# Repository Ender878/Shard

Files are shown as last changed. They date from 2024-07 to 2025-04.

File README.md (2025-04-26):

# Shard - Custom ESP32 S3 Board :electron:

Shard_png2

**Shard** is an open source **ESP32 S3** board that I designed as a summer project to learn more about electronics and PCB design.

## Core features:

- 16MB Flash
- WiFi and Bluethoot capabilities
- Built-in Neopixel RGB LED
- 21 configurable GPIO pins
- Up to 16V for external Power supply
- UART & Configurable SPI and I2C pins

The board itself is pretty small, 4.6x4.8cm and doesn't have mounting holes unfortunately. It is designed to be an all-feature development board for prototyping.

## Programming

### Uploading

The board doesn't come with a **USB-UART bridge**, so the firmware uploading requires user input:

- When the uploading process starts, hold the **RESET** button
- Immediately after you pressed it, press the **BOOT** button and then release the **RESET** button
- After the code is uploaded, press the **RESET** button again to exit Download Mode, so that the board can execute the code.

### Programming with Arduino IDE 2

To program this board with the **Arduino IDE**, you have to:
- Install the "esp32" board manager.
- then select the **UM-PROS3** board 
- when uploading, follow the steps listed in the **[Uploading](#uploading)** section.

### Programming with PlatformIO (recommended)

To program this board with **PlatformIO**, you should configure the **platformio.ini** file as follows:

~~~ini
[env:esp32-s3-devkitc-1]
platform = espressif32
board = shard
framework = arduino
~~~

I made a custom **board** config file for PlatformIO that specifies all the board's specifications. To use it, create a folder called **boards** and copy [this file](./shard.json) under it.

Also, this is the partition I used:

~~~csv
# Name,   Type, SubType, Offset,  Size, Flags
nvs,      data, nvs,     0x9000,  0x5000,
otadata,  data, ota,     0xe000,  0x2000,
app0,     app,  ota_0,   0x10000, 0x700000,
app1,     app,  ota_1,   0x710000,0x700000,
spiffs,   data, spiffs,  0xe10000,0x1F0000,
~~~

PlatformIO should find the board automatically. When uploading, still follow the steps in the **[Uploading](#uploading)** section.

## Reference

To design this board, I mainly referred to the Espressif's [ESP32-S3 Hardware Design Guidelines](https://docs.espressif.com/projects/esp-hardware-design-guidelines/en/latest/esp32s3/esp-hardware-design-guidelines-en-master-esp32s3.pdf).

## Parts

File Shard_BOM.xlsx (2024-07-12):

Comment | Designator | Footprint | JLCPCB Part #（optional）
~ | ANT1 | RF_Antenna:Texas_SWRA117D_2.4GHz_Right
1uF | C1 | Capacitor_SMD:C_0201_0603Metric | C5209398
2.2uF | C2 | Capacitor_SMD:C_0402_1005Metric | C386078
1uF | C3 | Capacitor_SMD:C_0201_0603Metric | C5209398
10nF | C4 | Capacitor_SMD:C_0201_0603Metric | C312126
10uF | C5 | Capacitor_SMD:C_0805_2012Metric | C100083
1uF | C6 | Capacitor_SMD:C_0402_1005Metric | C325464
0.1uF | C7 | Capacitor_SMD:C_0402_1005Metric | C312123
0.1uF | C8 | Capacitor_SMD:C_0402_1005Metric | C312123
1uF | C9 | Capacitor_SMD:C_0201_0603Metric | C5209398
0.1uF | C10 | Capacitor_SMD:C_0201_0603Metric | C312124
0.1uF | C11 | Capacitor_SMD:C_0201_0603Metric | C312124
0.1uF | C12 | Capacitor_SMD:C_0201_0603Metric | C312124
1uF | C13 | Capacitor_SMD:C_0201_0603Metric | C5209398
2.2uF | C14 | Capacitor_SMD:C_0402_1005Metric | C386078
1uF | C15 | Capacitor_SMD:C_0201_0603Metric | C5209398
0.1uF | C16 | Capacitor_SMD:C_0201_0603Metric | C312124
20pF | C17 | Capacitor_SMD:C_0201_0603Metric | C426053
20pF | C18 | Capacitor_SMD:C_0201_0603Metric | C426053
3pF | C19 | Capacitor_SMD:C_0201_0603Metric | C508850
2.7pF | C20 | Capacitor_SMD:C_0402_1005Metric | C386137
SS34 | D1 | Diode_SMD:D_SMA | C8678
SS34 | D2 | Diode_SMD:D_SMA | C8678
LED | D3 | LED_SMD:LED_0805_2012Metric | C2297
WS2812B | D4 | LED_SMD:LED_WS2812B-2020_PLCC4_2.0x2.0mm | C965555
USB_C_Receptacle_USB2.0_16P | J1 | Connector_USB:USB_C_Receptacle_GCT_USB4105-xx-A_16P_TopMnt_Horizontal | C2927038
Conn_01x08 | J2 | Connector_PinSocket_2.54mm:PinSocket_1x08_P2.54mm_Vertical
Conn_01x08 | J3 | Connector_PinSocket_2.54mm:PinSocket_1x08_P2.54mm_Vertical
Conn_01x08 | J4 | Connector_PinSocket_2.54mm:PinSocket_1x08_P2.54mm_Vertical
Conn_01x08 | J5 | Connector_PinSocket_2.54mm:PinSocket_1x08_P2.54mm_Vertical
2nH | L1 | Inductor_SMD:L_0201_0603Metric | C415347
2.4nH | L2 | Inductor_SMD:L_0201_0603Metric | C87200
5.1k | R1 | Resistor_SMD:R_0402_1005Metric | C294638
5.1k | R2 | Resistor_SMD:R_0402_1005Metric | C294638
220 | R3 | Resistor_SMD:R_0805_2012Metric | C2771036
10k | R4 | Resistor_SMD:R_0402_1005Metric | C3152101
100k | R5 | Resistor_SMD:R_1210_3225Metric | C304940
0 | R6 | Resistor_SMD:R_0201_0603Metric | C965347
0 | R7 | Resistor_SMD:R_0201_0603Metric | C965347
0 | R8 | Resistor_SMD:R_0201_0603Metric | C965347
0 | R9 | Resistor_SMD:R_0201_0603Metric | C965347
0 | R10 | Resistor_SMD:R_0201_0603Metric | C965347
22 | R11 | Resistor_SMD:R_0201_0603Metric | C306975
499 | R12 | Resistor_SMD:R_0805_2012Metric | C17722
BOOT | BOOT | Button_Switch_SMD:SW_Push_SPST_NO_Alps_SKRK | C720477
RESET | RESET | Button_Switch_SMD:SW_Push_SPST_NO_Alps_SKRK | C720477
ESP32-S3 | U1 | Package_DFN_QFN:QFN-56-1EP_7x7mm_P0.4mm_EP4x4mm | C2913194
USBLC6-2P6 | U2 | Package_TO_SOT_SMD:SOT-666 | C2827693
TLV76733DRVx | U3 | Package_SON:WSON-6-1EP_2x2mm_P0.65mm_EP1x1.6mm_ThermalVias | C2848334
TLV76733DRVx | U4 | Package_SON:WSON-6-1EP_2x2mm_P0.65mm_EP1x1.6mm_ThermalVias | C2848334
W25Q128JVS | U5 | Package_SO:SOIC-8_5.23x5.23mm_P1.27mm | C97521
40Mhz | Y1 | Crystal:Crystal_SMD_2520-4Pin_2.5x2.0mm | C409423

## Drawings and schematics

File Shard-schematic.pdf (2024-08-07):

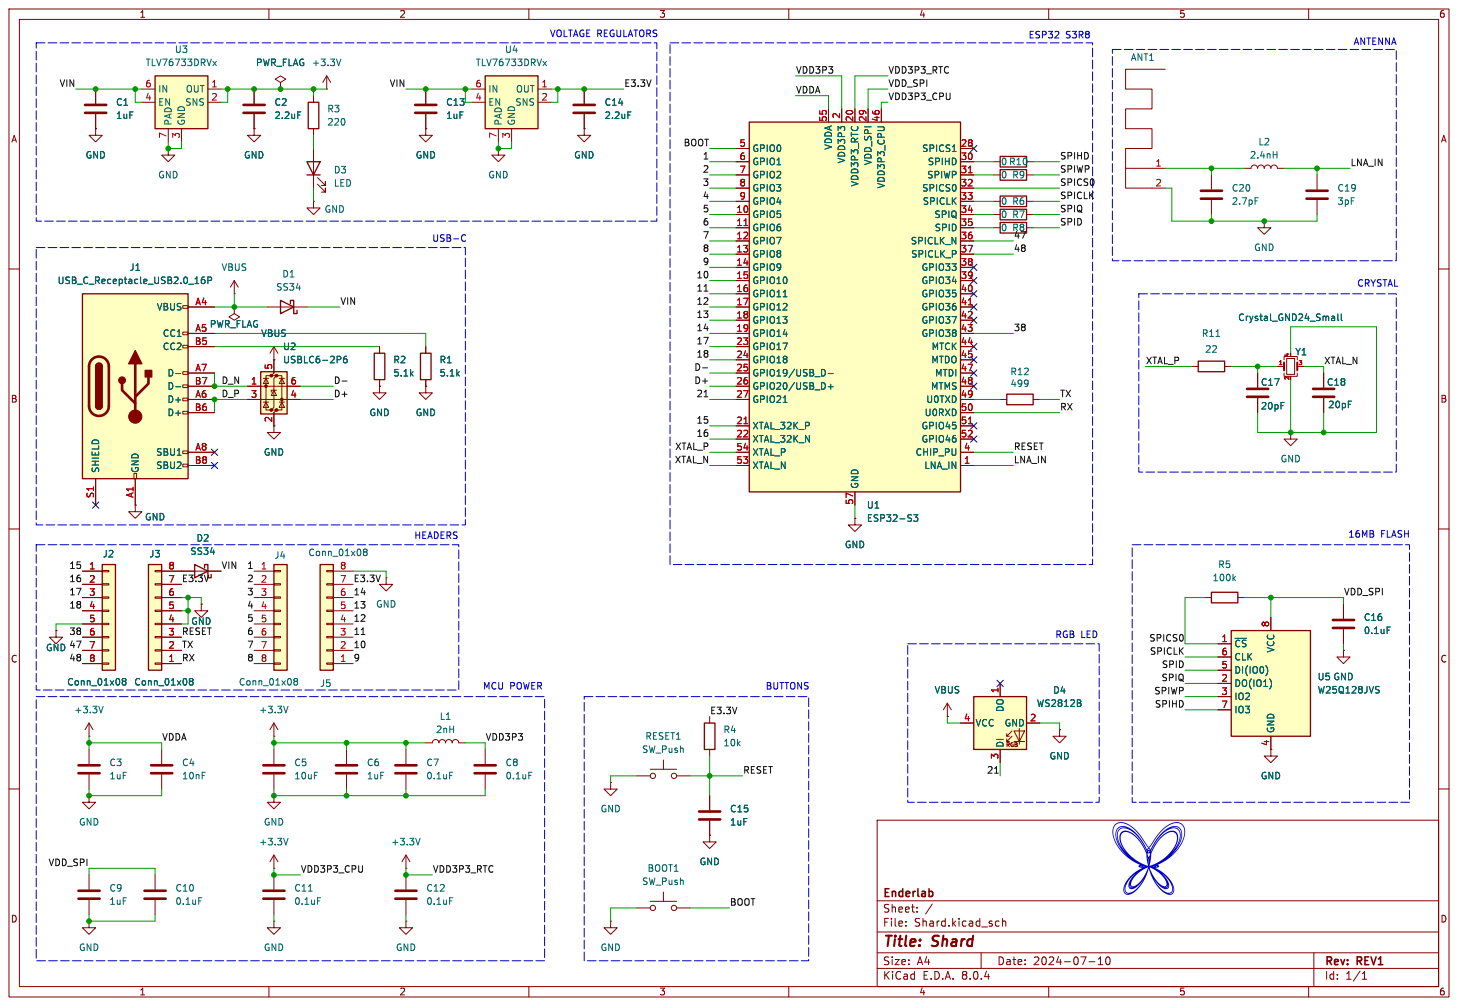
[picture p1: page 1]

2 VDD3P3_RTC 20 XTAL_32K_P 21 XTAL_32K_N 22 GPIO17 23 GPIO18 24 GPIO19/USB_D- 25 GPIO20/USB_D+ 26 GPIO21 27 SPICS1 28 VDD_SPI 29 SPIHD 30 SPIWP 31 SPICS0 32 SPICLK 33 SPIQ 34 SPID 35 SPICLK_P 37 GPIO33 38 GPIO34 39 CHIP_PU 4 GPIO35 40 GPIO36 41 GPIO37 42 GPIO38 43 MTCK 44 VDD3P3_CPU 46 MTDI 47 MTMS 48 U0TXD 49 GPIO0 5 U0RXD 50 GPIO46 52 XTAL_N 53 XTAL_P 54 VDDA 55 GND 57 GPIO1 6 GPIO2 7 GPIO3 8 GPIO4 9 GND GND GND GND GND

2 VDD3P3_RTC 20 XTAL_32K_P 21 XTAL_32K_N 22 GPIO17 23 GPIO18 24 GPIO19/USB_D- 25 GPIO20/USB_D+ 26 GPIO21 27 SPICS1 28 VDD_SPI 29 SPIHD 30 SPIWP 31 SPICS0 32 SPICLK 33 SPIQ 34 SPID 35 SPICLK_P 37 GPIO33 38 GPIO34 39 CHIP_PU 4 GPIO35 40 GPIO36 41 GPIO37 42 GPIO38 43 MTCK 44 VDD3P3_CPU 46 MTDI 47 MTMS 48 U0TXD 49 GPIO0 5 U0RXD 50 GPIO46 52 XTAL_N 53 XTAL_P 54 VDDA 55 GND 57 GPIO1 6 GPIO2 7 GPIO3 8 GPIO4 9 U1ESP32-S3

1 GND 2 DI 3 VCC 4 D4 WS2812B GND GND

1 GND 2 DI 3 VCC 4 GND

File: Shard.kicad_sch Sheet: / Enderlab

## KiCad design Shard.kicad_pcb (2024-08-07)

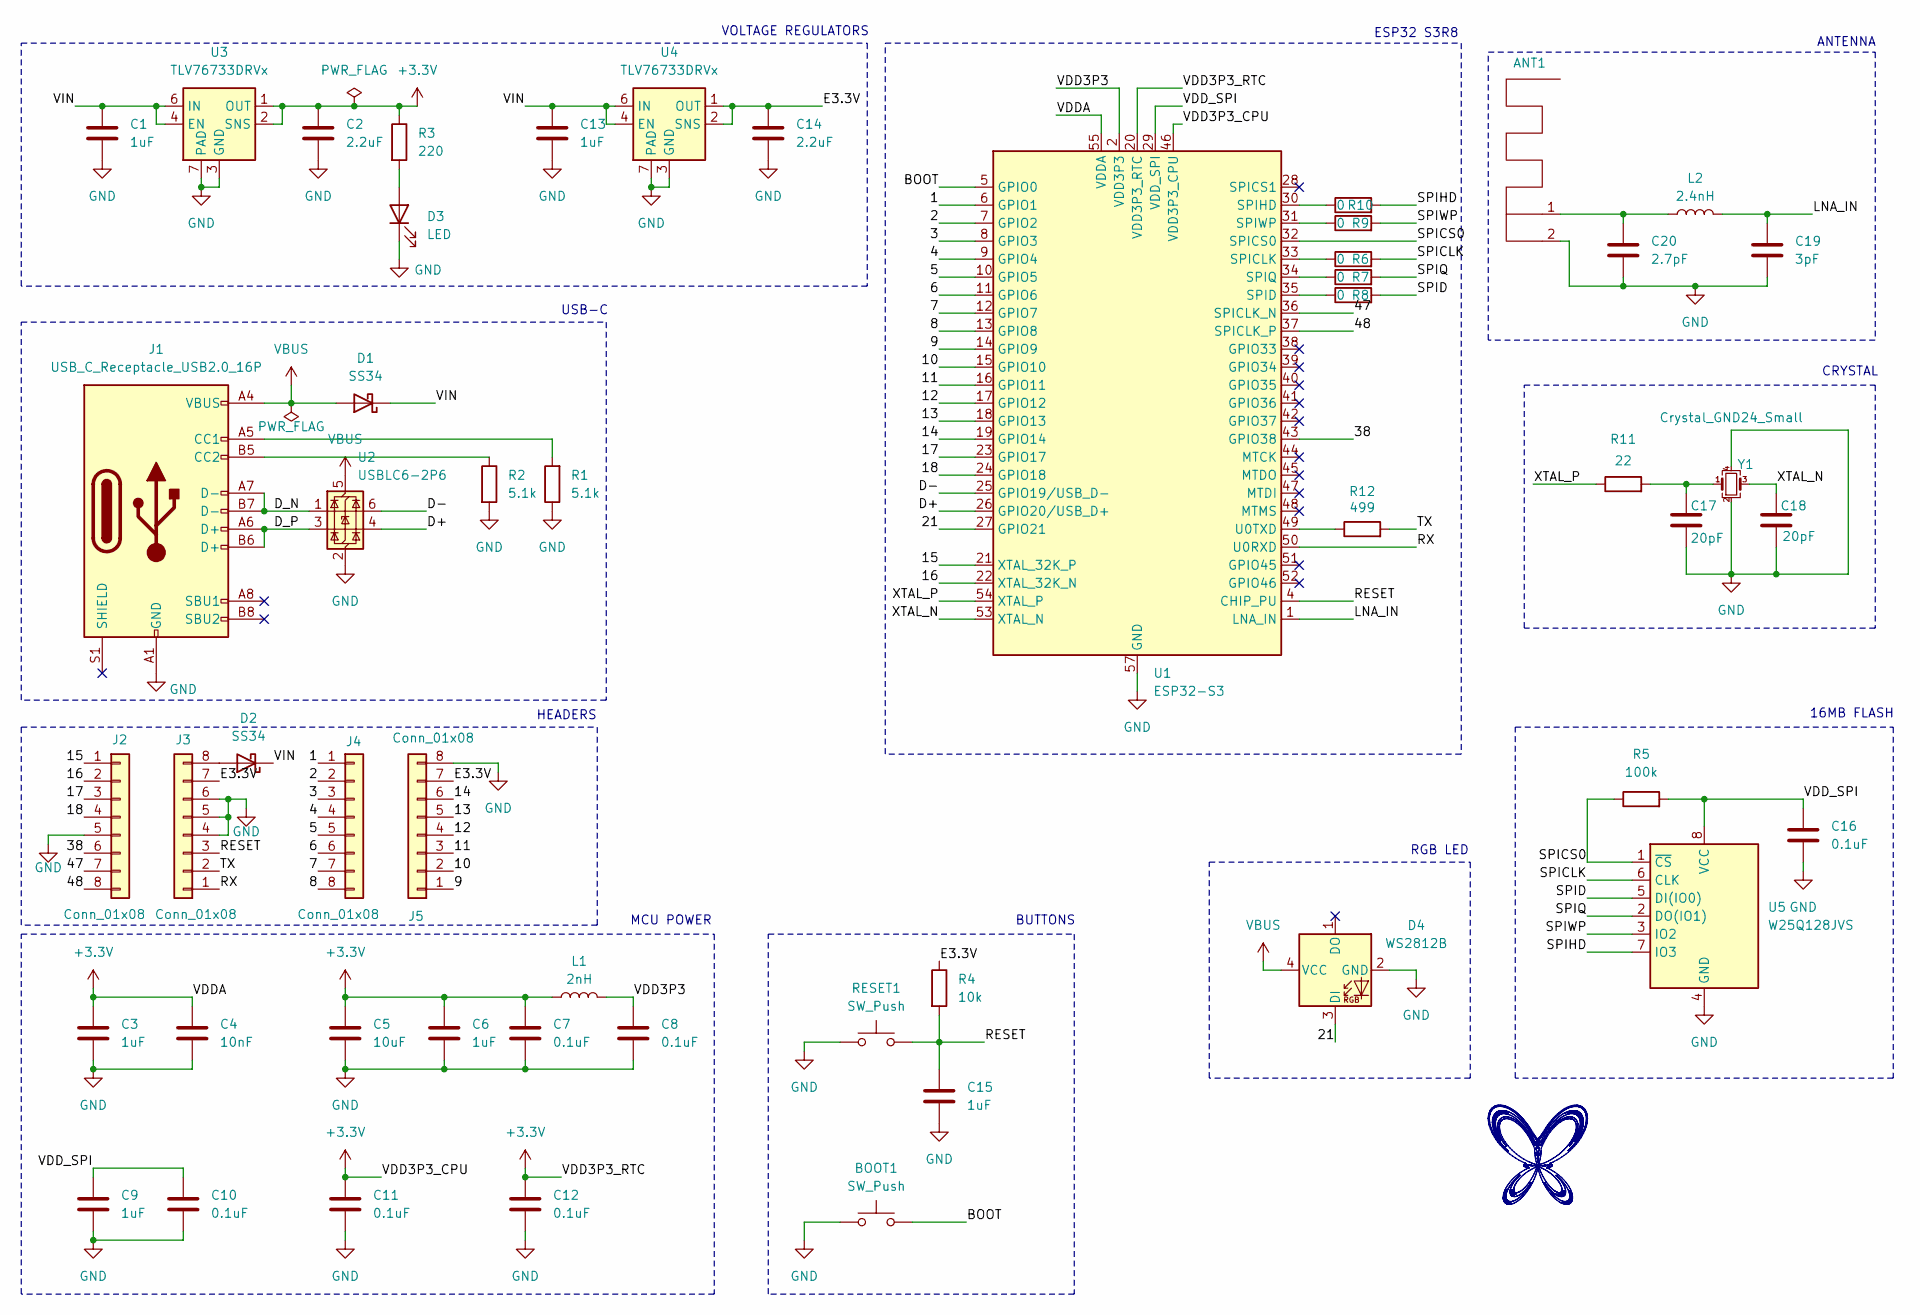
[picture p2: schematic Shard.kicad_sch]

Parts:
ANT1: Texas_SWRA117D_2.4GHz_Right
BOOT1: SW_Push; SW_Push_SPST_NO_Alps_SKRK
C1, C3, C9, C13, C15: 1uF; C_0201_0603Metric
C2, C14: 2.2uF; C_0402_1005Metric
C4: 10nF; C_0201_0603Metric
C5: 10uF; C_0805_2012Metric
C6: 1uF; C_0402_1005Metric
C7, C8: 0.1uF; C_0402_1005Metric
C10, C11, C12, C16: 0.1uF; C_0201_0603Metric
C17, C18: 20pF; C_0201_0603Metric
C19: 3pF; C_0201_0603Metric
C20: 2.7pF; C_0402_1005Metric
D1, D2: SS34; D_SMA
D3: LED; LED_0805_2012Metric
D4: WS2812B; LED_WS2812B-2020_PLCC4_2.0x2.0mm
J1: USB_C_Receptacle_USB2.0_16P; USB_C_Receptacle_GCT_USB4105-xx-A_16P_TopMnt_Horizontal
J2, J3, J4, J5: Conn_01x08; PinSocket_1x08_P2.54mm_Vertical
L1: 2nH; L_0201_0603Metric
L2: 2.4nH; L_0201_0603Metric
R1, R2: 5.1k; R_0402_1005Metric
R3: 220; R_0805_2012Metric
R4: 10k; R_0402_1005Metric
R5: 100k; R_1210_3225Metric
R6, R7, R8, R9, R10: 0; R_0201_0603Metric
R11: 22; R_0201_0603Metric
R12: 499; R_0805_2012Metric
RESET1: SW_Push; SW_Push_SPST_NO_Alps_SKRK
U1: ESP32-S3; QFN-56-1EP_7x7mm_P0.4mm_EP4x4mm
U2: USBLC6-2P6; SOT-666
U3, U4: TLV76733DRVx; WSON-6-1EP_2x2mm_P0.65mm_EP1x1.6mm_ThermalVias
U5: W25Q128JVS; SOIC-8_5.23x5.23mm_P1.27mm
Y1: Crystal_GND24_Small; Crystal_SMD_2520-4Pin_2.5x2.0mm

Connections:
+3.3V: C2.1, C3.1, C4.1, C5.1, C6.1, C7.1, C11.1, C12.1, L1.1, R3.1, U1.20 (VDD3P3_RTC), U1.46 (VDD3P3_CPU), U1.55 (VDDA), U1.56 (VDDA), U3.1 (OUT), U3.2 (SNS)
/1: J4.1, U1.6 (GPIO1)
/2: J4.2, U1.7 (GPIO2)
/3: J4.3, U1.8 (GPIO3)
/4: J4.4, U1.9 (GPIO4)
/5: J4.5, U1.10 (GPIO5)
/6: J4.6, U1.11 (GPIO6)
/7: J4.7, U1.12 (GPIO7)
/8: J4.8, U1.13 (GPIO8)
/9: J5.1, U1.14 (GPIO9)
/10: J5.2, U1.15 (GPIO10)
/11: J5.3, U1.16 (GPIO11)
/12: J5.4, U1.17 (GPIO12)
/13: J5.5, U1.18 (GPIO13)
/14: J5.6, U1.19 (GPIO14)
/15: J2.1, U1.21 (XTAL_32K_P)
/16: J2.2, U1.22 (XTAL_32K_N)
/17: J2.3, U1.23 (GPIO17)
/18: J2.4, U1.24 (GPIO18)
/21: D4.3 (DI), U1.27 (GPIO21)
/38: J2.6, U1.43 (GPIO38)
/47: J2.7, U1.36 (SPICLK_N)
/48: J2.8, U1.37 (SPICLK_P)
/BOOT: BOOT1.2, U1.5 (GPIO0); also elsewhere on the board
/D+: U1.26 (GPIO20/USB_D+), U2.4 (I/O2)
/D-: U1.25 (GPIO19/USB_D-), U2.6 (I/O1)
/D_N: J1.A7 (D-), J1.B7 (D-), U2.1 (I/O1)
/D_P: J1.A6 (D+), J1.B6 (D+), U2.3 (I/O2)
/E3.3V: C14.1, J3.7, J5.7, R4.1, U4.1 (OUT), U4.2 (SNS)
/LNA_IN: C19.1, L2.2, U1.1 (LNA_IN)
/RESET: C15.1, J3.3, R4.2, RESET1.2, U1.4 (CHIP_PU); also elsewhere on the board
/RX: J3.1, U1.50 (U0RXD)
/SPICLK: R6.2, U5.6 (CLK)
/SPICS0: R5.1, U1.32 (SPICS0), U5.1 (~CS)
/SPID: R8.2, U5.5 (DI(IO0))
/SPIHD: R10.2, U5.7 (IO3)
/SPIQ: R7.2, U5.2 (DO(IO1))
/SPIWP: R9.2, U5.3 (IO2)
/TX: J3.2, R12.2
/VDD3P3: C8.1, L1.2, U1.2 (VDD3P3), U1.3 (VDD3P3)
/VDD_SPI: C9.1, C10.1, C16.1, R5.2, U1.29 (VDD_SPI), U5.8 (VCC)
/VIN: C1.1, C13.1, D1.1 (K), D2.1 (K), U3.4 (EN), U3.6 (IN), U4.4 (EN), U4.6 (IN)
/XTAL_N: C18.1, U1.53 (XTAL_N), Y1.3
/XTAL_P: R11.1, U1.54 (XTAL_P)
GND: ANT1.2, BOOT1.1, C1.2, C2.2, C3.2, C4.2, C5.2, C6.2, C7.2, C8.2, C9.2, C10.2, C11.2, C12.2, C13.2, C14.2, C15.2, C16.2, C17.2, C18.2, C19.2, C20.2, D3.1 (K), D4.2 (GND), J1.A1 (GND), J1.A12 (GND), J1.B1 (GND), J1.B12 (GND), J2.5, J3.4, J3.5, J3.6, J5.8, R1.1, R2.2, RESET1.1, U1.57 (GND), U2.2 (GND), U3.3 (GND), U3.5 (GND), U3.7 (PAD), U4.3 (GND), U4.5 (GND), U4.7 (PAD), U5.4 (GND), Y1.2, Y1.4; also elsewhere on the board
unnamed: ANT1.1, C20.1, L2.1
unnamed: C17.1, R11.2, Y1.1
unnamed: D2.2 (A), J3.8
unnamed: D3.2 (A), R3.2
unnamed: J1.A5 (CC1), R1.2
unnamed: J1.B5 (CC2), R2.1
unnamed: R6.1, U1.33 (SPICLK)
unnamed: R8.1, U1.35 (SPID)
unnamed: R10.1, U1.30 (SPIHD)
unnamed: R7.1, U1.34 (SPIQ)
unnamed: R9.1, U1.31 (SPIWP)
unnamed: R12.1, U1.49 (U0TXD)
VBUS: D1.2 (A), D4.4 (VCC), J1.A4 (VBUS), J1.A9 (VBUS), J1.B4 (VBUS), J1.B9 (VBUS), U2.5 (VBUS)

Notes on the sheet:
CRYSTAL
HEADERS
MCU POWER
16MB FLASH
ANTENNA
USB-C
RGB LED
ESP32 S3R8
BUTTONS
VOLTAGE REGULATORS

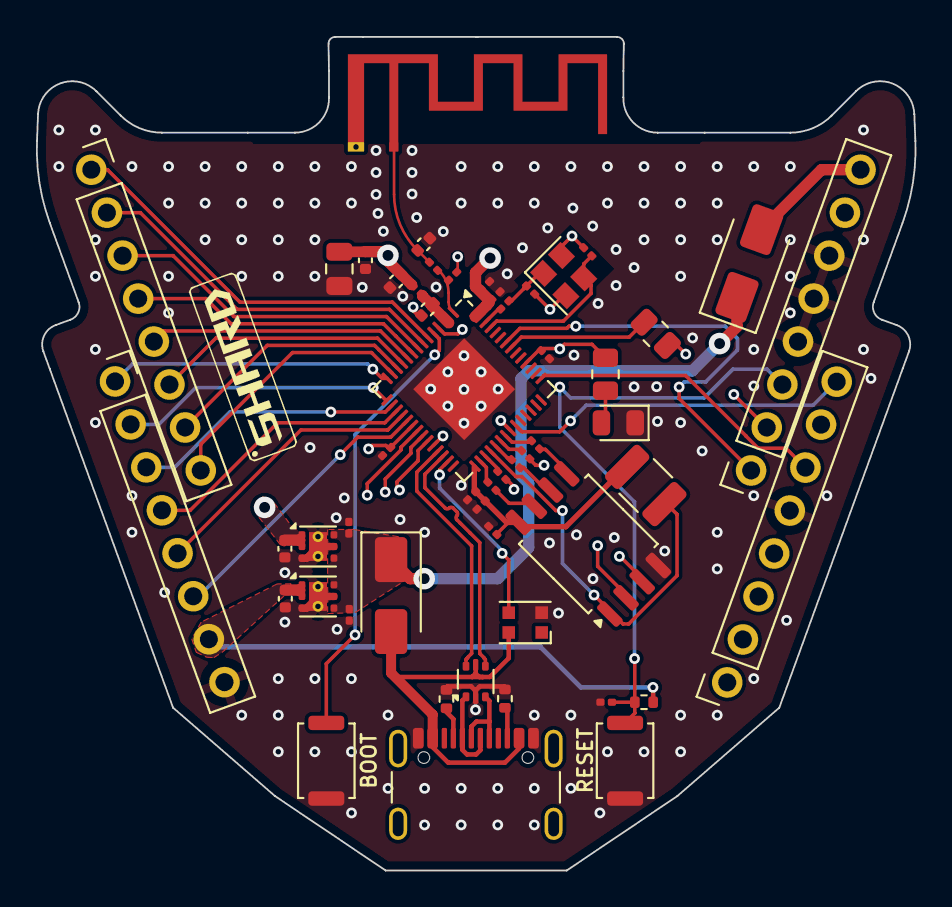
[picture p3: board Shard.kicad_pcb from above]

Board: 4 copper layers, 48.8 x 46.3 mm, 52 parts (0 on the bottom side), 58 nets.

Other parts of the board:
BOOT: SW_Push; SW_Push_SPST_NO_Alps_SKRK
RESET: SW_Push; SW_Push_SPST_NO_Alps_SKRK

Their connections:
/BOOT: BOOT.2; also elsewhere on the board
/RESET: RESET.2; also elsewhere on the board
GND: BOOT.1, RESET.1; also elsewhere on the board

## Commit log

2024-06-30 Add USB & ESP32 S3 symbols + initial usb wiring.
    [Shard.kicad_sch]
2024-06-30 USB-C Wiring
    [Shard.kicad_sch]
2024-06-30 Add voltage regulator
    [Shard.kicad_sch]
2024-06-30 Add battery connector
    [Shard.kicad_sch]
2024-06-30 Add missing footprint and parts
    [Shard.kicad_sch]
2024-07-01 Add MCU power schematic + Footprint and part assignation
    [Shard.kicad_sch]
2024-07-01 Add missing inductor footprint + LDO for external 3.3V alimentation.
    [Shard.kicad_sch]
2024-07-01 Add Reset & boot buttons (footprints and parts associated)
    [Shard.kicad_sch]
2024-07-01 Add 16MB Flash with footprint & part
    [Shard.kicad_sch]
2024-07-01 Add Crystal Oscillator.
    [Shard.kicad_sch]
2024-07-01 Finish crystal scheme, started GPIO labeling
    [Shard.kicad_sch]
2024-07-02 GPIO pin labeling
    [Shard.kicad_sch]
2024-07-02 Add RF circuit
    [Shard.kicad_sch]
2024-07-02 Add RF Antenna footprint
    [Shard.kicad_sch]
2024-07-02 Finished schematic with headers
    [Shard.kicad_sch]
2024-07-03 USB-C PCB routing
    [Shard.kicad_pcb, Shard.kicad_sch]
2024-07-04 Finish initial PCB Layout
    [Shard.kicad_pcb, Shard.kicad_sch]
2024-07-05 Started routing USB & Power
    [Shard.kicad_pcb, Shard.kicad_sch]
2024-07-06 Completed Power routing
    [Shard.kicad_pcb, Shard.kicad_sch]
2024-07-06 Routed SPI traces
    [Shard.kicad_pcb]
2024-07-06 RF routing and impedence matching
    [Shard.kicad_pcb]
2024-07-07 Routed most GPIO pins
    [Shard.kicad_pcb, Shard.kicad_sch]
2024-07-07 Finished routing
    [Shard.kicad_pcb, Shard.kicad_sch]
2024-07-07 Add PCB margin
    [Shard.kicad_pcb]
2024-07-09 Add stitching vias, checked DRC rules
    [Shard.kicad_pcb, Shard.kicad_sch]
2024-07-09 Add pinout to bottom silkscreen
    [Shard.kicad_pcb]
2024-07-10 Add production files
    [Shard-B_Cu.gbr, Shard-B_Mask.gbr, Shard-B_Paste.gbr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]
2024-07-12 Fixed some things
    [Shard-B_Cu.gbr, Shard-B_Mask.gbr, Shard-B_Paste.gbr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]
2024-08-07 Fix design errors & update README
    [Shard-B_Cu.gbr, Shard-B_Mask.gbr, Shard-B_Paste.gbr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]
